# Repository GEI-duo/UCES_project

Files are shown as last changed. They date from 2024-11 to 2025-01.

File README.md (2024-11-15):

# UCES_project

## Parts

### Meeple

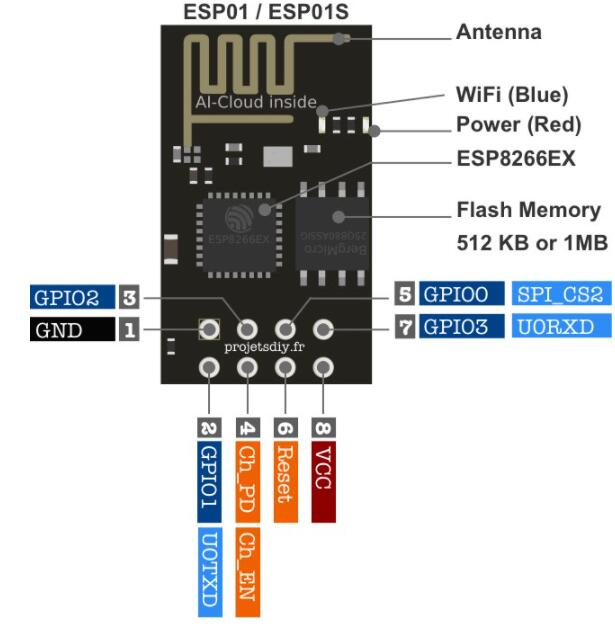
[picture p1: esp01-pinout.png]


#### Hardware

-   ESP-01 (ESP8266)
-   ESP-01 Programmer module
-   ESP-01 Bredboard adapter
-   Mini bredboard
-   Hall sensor (A3144)
-   Resistors
-   LED
-   Set of wires

### Operation base

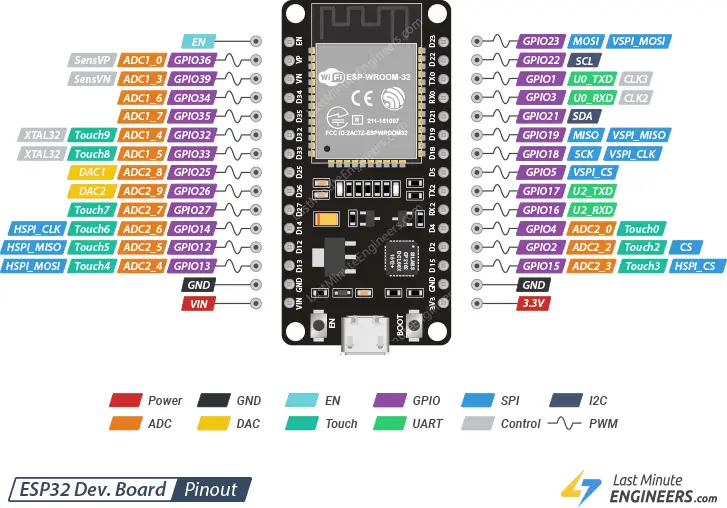
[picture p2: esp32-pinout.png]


#### Hardware

-   ESP-32
-   LCD Display
-   I2C - LCD Adapter
-   Buzzer
-   Push button
-   Resistors
-   Set of wires
-   Large bredboard

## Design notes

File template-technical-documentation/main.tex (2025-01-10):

\documentclass[11pt]{article}
\linespread{1.5}

% SELECT LANGUAGE:
\usepackage{preamble}
% \usepackage[spanish]{preamble}

% Help LaTeX Workshop citation browser parser
\iffalse
\addbibresource{bibliography.bib} 
\fi

\begin{document}

{
\pagenumbering{gobble} % Remove page numbering
\hypersetup{hidelinks} % Hide link colors

% Title
\subfile{title}

% Abstract
% \subfile{abstract}

\newpage

% Table of Contents
\tableofcontents
\clearpage

% List of *
% \tcblistof[\section*]{code}{\codListTitle}                    % codes
% \tcblistof[\section*]{theorem}{\theoListTitle}                % theorems
% \renewcommand{\listfigurename}{\figListTitle}\listoffigures   % figures
% \renewcommand\listtablename{\tabListTitle}\listoftables       % tables
}

\clearpage
\pagenumbering{arabic} % Add page numbering

% ------------------------- CONTENT ------------------------- %

\subfile{sections/wiring-schematic}
\subfile{sections/mqtt-topics}

% ---------------------------------------------------------- %

% Acronyms
% \printglossary[type=\acronymtype, title=\acrTitle]

% Special terms
% \printglossary[title=\terTitle]

% Bibliography
% \printbibliography[heading=bibintoc, title=\bibTitle]
% \clearpage

% Appendix
% \subfile{appendix}

\end{document}

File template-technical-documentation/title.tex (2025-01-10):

\documentclass[../main.tex]{subfiles}

\begin{document}

\begin{titlepage}
    \begin{minipage}[c]{0.4\linewidth}
    Universitat de Lleida \\
    Enginyeria Informàtica \\
    Embedded and Ubiquitous Systems \\
    Prof. Fernando Guirado Fernández
    \end{minipage}
    \hfill
    \begin{minipage}[c]{0.5\linewidth}
    \hfill
    
    \end{minipage}
        
    \vspace{5cm}

     \begin{center}
        \Huge
        \textbf{e-Game Board} \\ Meeple Showdown \\ \LARGE Technical Documentation
     \end{center}        
            
    \vspace{5cm}
        
    \begin{flushright}
        \large
        Jordi García Ventura \\
        Christian López García
    \end{flushright}
        
    \vfill
        
    \begin{center}
        \today
    \end{center}
\end{titlepage}

\end{document}

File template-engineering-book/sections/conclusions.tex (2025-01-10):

\documentclass[../main.tex]{subfiles}

\begin{document}

\section{Conclusions}

The game we developed is functional, but it currently does not account for certain unpredictable player behaviors, such as publishing to topics at inappropriate times.

Developing with microcontrollers is undoubtedly challenging, yet we successfully created an engaging and enjoyable game that integrates all the essential components of an embedded system. Additionally, we achieved interconnectivity among multiple devices through networking, unlocking numerous possibilities for future projects. For instance, the network capabilities could be leveraged to input user data via a captive portal rather than hardcoding network credentials into the source code. Another potential enhancement could be implementing Over-The-Air (OTA) updates, allowing remote updates to the devices' firmware.

A significant challenge we faced was establishing a robust communication standard, including a well-defined contract and MQTT topic structure, to ensure seamless interaction between devices. This standardization enabled different teams to work independently while ensuring all components integrated cohesively. Achieving this required a clear understanding of the project requirements and the components involved.

One obstacle that slowed our progress was the time required for compiling and uploading code to the microcontrollers, particularly with the ESP-01, which requires flashing via a USB-to-Serial adapter. Using a development-friendly board with a micro-USB interface could have expedited our iteration process. Once the code reached a more stable state, we could then transition to the ESP-01 for deployment.

Overall, this project provided valuable insights into the complexities of embedded systems and offered a foundation for exciting future developments.

\end{document}

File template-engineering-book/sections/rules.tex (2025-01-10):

\documentclass[../main.tex]{subfiles}

\begin{document}

\section{e-Game Rules}

\subsection{Objective}

Be the last surviving meeple on the board.

\subsection{Players}

Each team consists of two people:
\begin{itemize}
    \item \textbf{Mover (Pawn Controller)}: Controls the movement of the meeple on the board.
    \item \textbf{Operator (Strategist)}: Makes decisions on whether to shoot or pass the bullet without seeing the board.
\end{itemize}

\subsection{Game Components}
\begin{itemize}
    \item \textbf{Magnetic board(s)}: Includes hidden magnets under each position.
    \item \textbf{Meeples (pawns)}: Each player team has one meeple. It has two LEDs: one for knowing who has the bullet and another for magnet detection feedback.
    \item \textbf{Operation Base}: Includes LCD display, push button, and other components for decisions made by operators.
    \item \textbf{Broker}: Handles the game logic and the state.
\end{itemize}

\subsection{Setup}
\begin{itemize}
    \item \textbf{Initial Meeple Placement}: Each pawn begins in a random position on the board. This is decided before the game starts.
    \item \textbf{Bullet Assignment}: One player is randomly assigned the Bullet at the start of the game.
\end{itemize}

\subsection{Gameplay Overview}
The game proceeds in rounds, with the following steps repeated until only one meeple remains:
\begin{enumerate}
    \item \textbf{Movement Phase:}
    \begin{itemize}
        \item Pawns move one space in one of four directions: up, down, left, or right.
        \item Movement order is decided randomly at the start of each round.
    \end{itemize}
    \item \textbf{Decision Phase:}
    \begin{itemize}
        \item The operator of the team with the Bullet decides if they want to shoot.
        \item The operator cannot see the board, but may communicate with other pawns (within 60 seconds).
        \item Shooting affects all meeples in the same row, column, or diagonal as the operator's meeple (Figure \ref{fig:shooting}).
        \begin{itemize}
            \item \textbf{Hit}: If the shot hits any meeples, they are eliminated.
            \item \textbf{Miss}: If no other meeple is hit, the shooting operator is eliminated.
        \end{itemize}
        \item If the operator chooses not to shoot, there is a small probability of dying.
    \end{itemize}
\end{enumerate}

\begin{figure}[!htb]
    \centering
    }\
    \caption{Shooting directions examples}
    \label{fig:shooting}
\end{figure}

\subsection{Additional Rules}
\begin{itemize}
    \item \textbf{Time Constraints}: Operators must decide to shoot or not within 60 seconds. If time runs out, the decision is to not shoot.
    \item \textbf{Lives}: Each meeple has 1 life. If they are hit, they are eliminated.
    \item \textbf{Random Player Selection}: When the bullet is reassigned, the game selects a random player who hasn’t been eliminated.
\end{itemize}

\subsection{End Condition}
The game continues until only one meeple remains. This team is declared the winner.

\end{document}

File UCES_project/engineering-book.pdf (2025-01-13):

Universitat de Lleida

Enginyeria Informàtica

Embedded and Ubiquitous Systems

Prof. Fernando Guirado Fernández

# e-Game Board

# Meeple Showdown

## Engineering Book

Jordi García Ventura

Christian López García

January 10, 2025

## Contents

## 1 Project Milestones

The project needs to be done between the 19th of October 2024 and the 13th of January 2025.

We identify ve main features that need to be developed:

- Game Design
- MQTT Broker
- Meeple
- Operation base
- Master

All the tasks, subtasks, time estimations and dependencies are shown in the Gantt chart in

Figure 1.

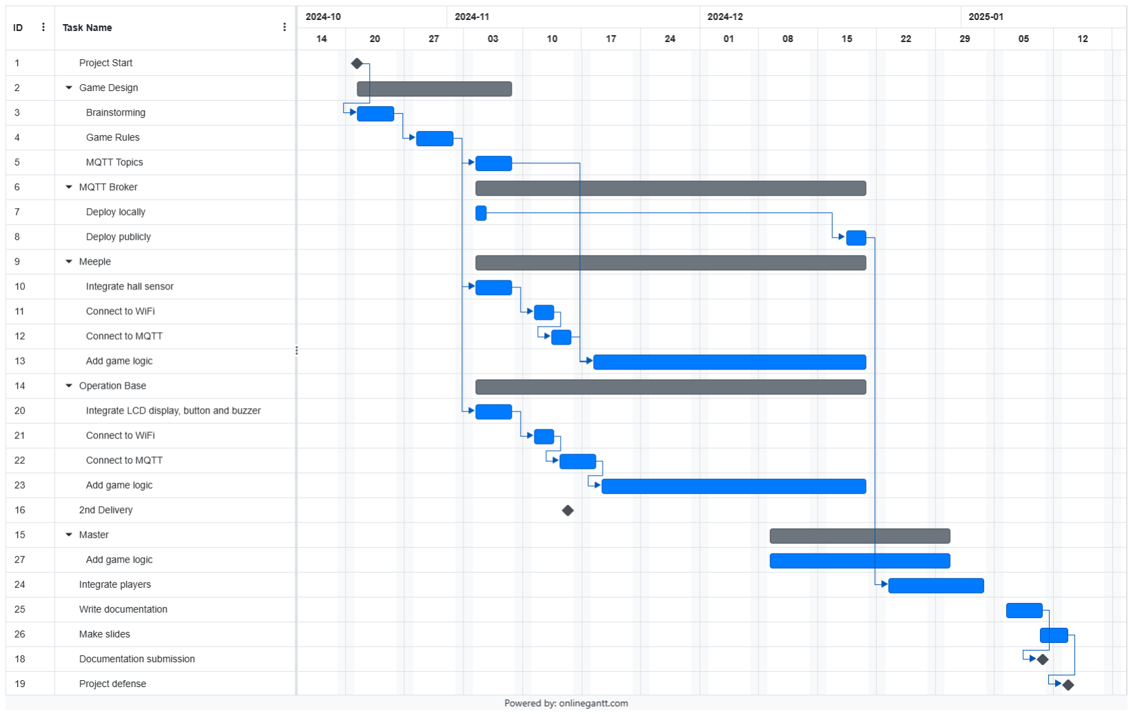
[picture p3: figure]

Figure 1: Gantt chart of the project

Regarding the asignations, the Game Design, Master and MQTT Broker are going to be

done by all members of the dierent teams. Then, each team is responsible of programming

their Meeple and Operation base. In our case, Christian will do the Meeple and Jordi will do the

Operation base.

Finally, we are going to expose the MQTT Broker in a public server in order to test the

communication between the devices of all the groups remotely.

## 2 Component Design

### 2.1 Meeple

The meeple is the component that represents the player’s position on the board and provides

feedback about player movement, death, and turn roles. It achieves this using two LEDs (a

green one and a yellow one) and a hall sensor. Communication with the game controller is

facilitated through the MQTT protocol.

The logic governing the meeple is depicted in Figure 2.

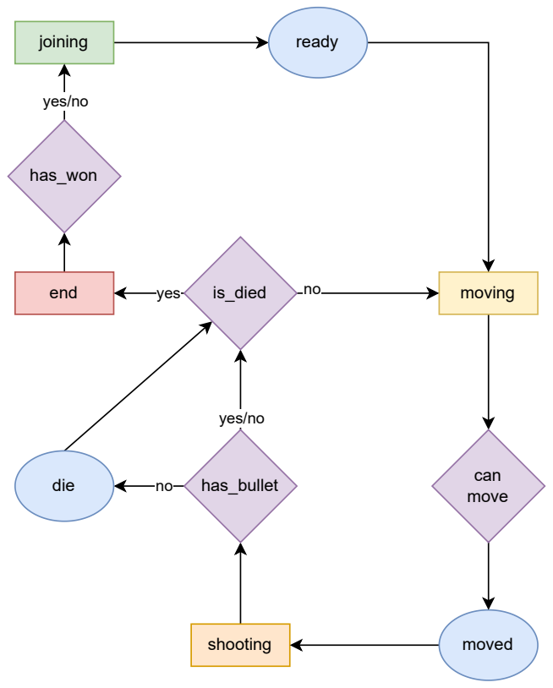
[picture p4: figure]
joining; moving; shooting; end; ready; moved; can move; yes/no; die; has_bullet; has_won; yes; is_died

Figure 2: Meeple logic ow diagram

Developing the meeple required approximately 10 hours and was completed solely by

Christian. While the component was relatively simple to design, my limited experience with

electronics and C++ made the process more time-consuming, particularly when trying to

create scalable and understandable code.

As mentioned earlier, the most challenging part was ensuring the C++ code worked as

intended. Another diculty was achieving the desired "blinking" eect for the green LED, which required ne-tuning to function properly.

### 2.2 Operation base

The operation base is responsible for determining, when it is its turn, whether the player should

shoot or not. Additionally, it provides feedback about the game state through an LCD display,

as the operator cannot directly see the game board.

The logic governing the operation base, which relies on MQTT topic subscription and

publication, is illustrated in Figure 3.

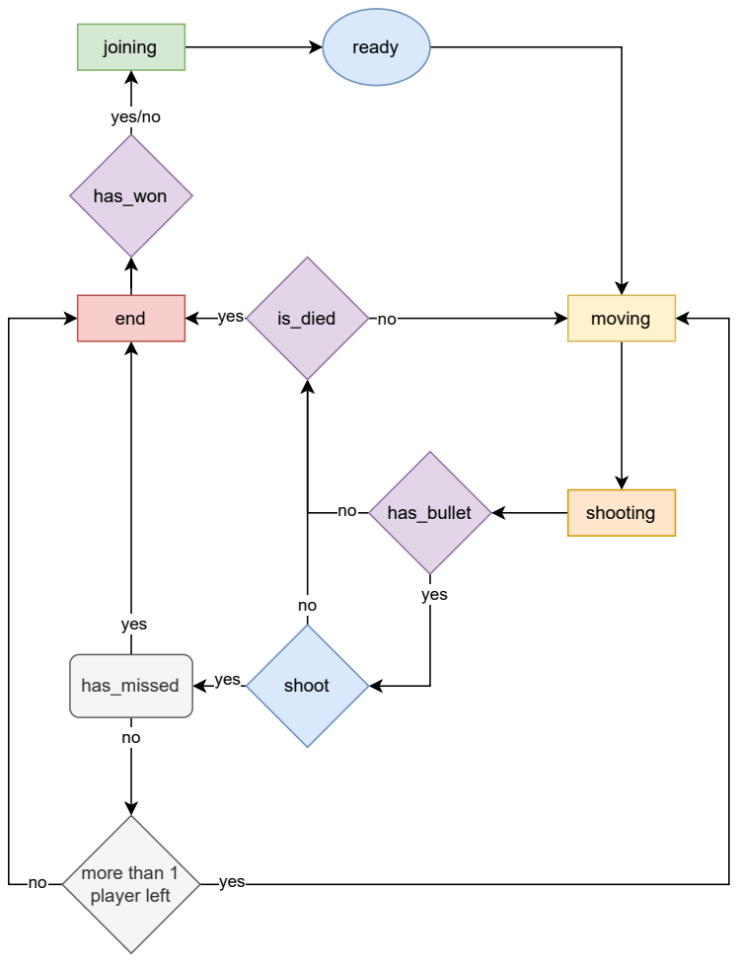
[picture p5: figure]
joining; ready; end; yes; has_bullet; moving; shooting; shoot; is_died; yes/no; has_won; has_missed; yes more than 1; player left

Figure 3: Operation base logic ow diagram

Developing the operation base required approximately 30 hours and was completed entirely

by Jordi.

Initially, all programming was done using Arduino. However, I later migrated most of the

code to FreeRTOS. During development, I encountered several challenges. One issue was with

the button, which behaved erratically. This was not solely due to switch bounce; interference

was also caused by the weak internal pull-up resistorsimply bringing a nger close to the button

without touching it aected the readings. Adding an external pull-up resistor resolved this

issue.

Another problem involved WiFi connectivity. The ESP32 module was unable to connect to

my network. After investigation, I discovered that the ESP32 does not support 5GHz networks,

requiring a switch to a 2.4GHz network.

I also faced diculties connecting to the MQTT broker. The issue stemmed from the

broker’s IP address changing, but the unclear error messages made diagnosing the problem

challenging.

Lastly, I dedicated considerable time to refactoring the code, improving its readability and

scalability for future maintenance and enhancements.

### 2.3 Game Controller

The game controller is the core component of the game, responsible for managing the game

ow, player turns, game state, and communication with the player feedback system. It operates

as a Docker container running a Python script that uses the MQTT protocol in a reactive

manner to enable bidirectional communication with the players.

The logic governing the game controller is illustrated in Figure 4.

Developing the game controller took approximately 20 hours and was completed solely by

Christian. We chose Python for the development because it didnt need to run on a microchip,

so performance wasnt a major concern. Additionally, Im more familiar with Python, despite

having no prior experience with the paho-mqtt library. The most challenging aspect was

designing a clean and maintainable project structure. I encountered issues with circular

imports while trying to make the code both modular and understandable, and I feel that I

struggled with this in some areas.

I developed the meeple and the game controller in parallel, which allowed me to test

communication between the two components. While this was benecial, I was unable to test

the game controller with any operation base, so Im uncertain if it functions as expected in that

regard.

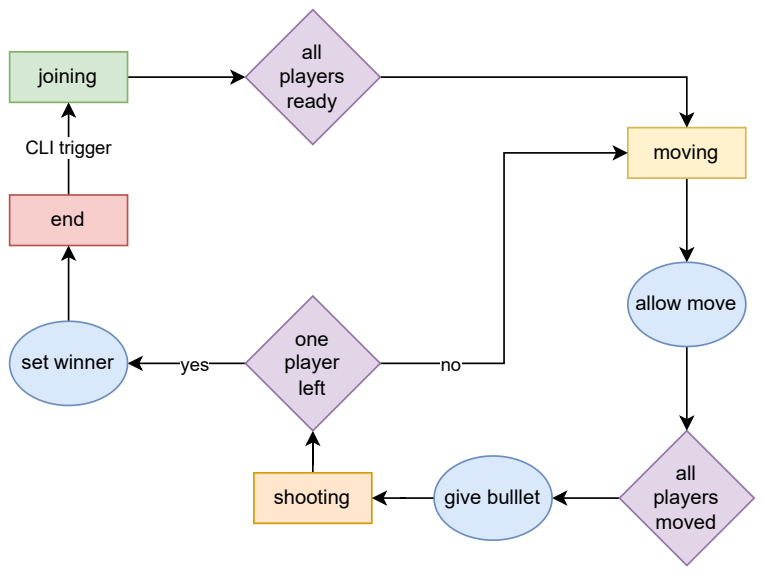
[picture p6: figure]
joining; moving; shooting; CLI trigger; end; all players ready; yes; one player left; all players moved; give bulllet; allow move; set winner

Figure 4: Master logic ow diagram

### 2.4 MQTT Broker

The MQTT broker is a critical component of the game, enabling seamless communication

between all other components. It operates as a Docker container running the Mosquitto MQTT

broker.

Developing the MQTT broker required approximately 4 hours and was completed solely by

Christian. The most challenging aspect was implementing authentication for the broker. The

team also encountered an issue where GitHub altered the line endings in conguration les

from LF to CRLF, which caused unexpected failures in the broker’s functionality.

Ultimately, Jordi deployed the broker to the cloud, allowing the team to test the game

remotely without needing to meet in person

## 3 e-Game Rules

### 3.1 Objective

Be the last surviving meeple on the board.

### 3.2 Players

Each team consists of two people:

- Mover (Pawn Controller): Controls the movement of the meeple on the board.
- Operator (Strategist): Makes decisions on whether to shoot or pass the bullet without

seeing the board.

### 3.3 Game Components

- Magnetic board(s): Includes hidden magnets under each position.
- Meeples (pawns): Each player team has one meeple. It has two LEDs: one for knowing

who has the bullet and another for magnet detection feedback.

- Operation Base: Includes LCD display, push button, and other components for decisions

made by operators.

- Broker: Handles the game logic and the state.

### 3.4 Setup

- Initial Meeple Placement: Each pawn begins in a random position on the board. This

is decided before the game starts.

- Bullet Assignment: One player is randomly assigned the Bullet at the start of the game.

### 3.5 Gameplay Overview

The game proceeds in rounds, with the following steps repeated until only one meeple remains:

1. Movement Phase:
- Pawns move one space in one of four directions: up, down, left, or right.
- Movement order is decided randomly at the start of each round.
2. Decision Phase:
- The operator of the team with the Bullet decides if they want to shoot.
- The operator cannot see the board, but may communicate with other pawns (within

60 seconds).

- Shooting aects all meeples in the same row, column, or diagonal as the operator’s

meeple (Figure 5).

– Hit: If the shot hits any meeples, they are eliminated.

– Miss: If no other meeple is hit, the shooting operator is eliminated.

- If the operator chooses not to shoot, there is a small probability of dying.

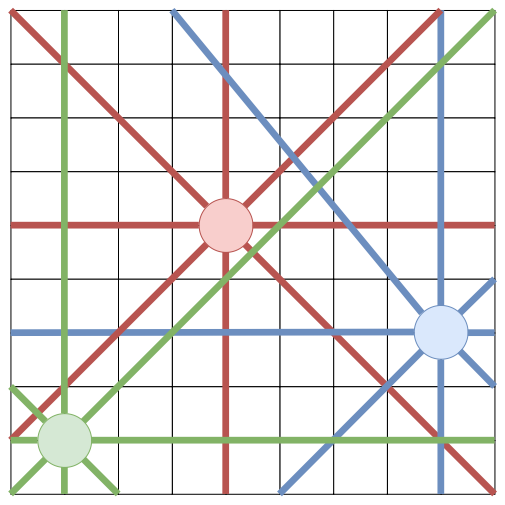
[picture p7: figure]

Figure 5: Shooting directions examples

### 3.6 Additional Rules

- Time Constraints: Operators must decide to shoot or not within 60 seconds. If time

runs out, the decision is to not shoot.

- Lives: Each meeple has 1 life. If they are hit, they are eliminated.
- Random Player Selection: When the bullet is reassigned, the game selects a random

player who hasnt been eliminated.

### 3.7 End Condition

The game continues until only one meeple remains. This team is declared the winner.

## 4 Conclusions

The game we developed is functional, but it currently does not account for certain unpredictable

player behaviors, such as publishing to topics at inappropriate times.

Developing with microcontrollers is undoubtedly challenging, yet we successfully created

an engaging and enjoyable game that integrates all the essential components of an embedded

system. Additionally, we achieved interconnectivity among multiple devices through network-

ing, unlocking numerous possibilities for future projects. For instance, the network capabilities

could be leveraged to input user data via a captive portal rather than hardcoding network

credentials into the source code. Another potential enhancement could be implementing

Over-The-Air (OTA) updates, allowing remote updates to the devices’ rmware.

A signicant challenge we faced was establishing a robust communication standard, includ-

ing a well-dened contract and MQTT topic structure, to ensure seamless interaction between

devices. This standardization enabled dierent teams to work independently while ensuring

all components integrated cohesively. Achieving this required a clear understanding of the

project requirements and the components involved.

One obstacle that slowed our progress was the time required for compiling and uploading

code to the microcontrollers, particularly with the ESP-01, which requires ashing via a USB-

to-Serial adapter. Using a development-friendly board with a micro-USB interface could have

expedited our iteration process. Once the code reached a more stable state, we could then

transition to the ESP-01 for deployment.

Overall, this project provided valuable insights into the complexities of embedded systems

and oered a foundation for exciting future developments.

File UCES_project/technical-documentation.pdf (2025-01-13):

Universitat de Lleida

Enginyeria Informàtica

Embedded and Ubiquitous Systems

Prof. Fernando Guirado Fernández

# e-Game Board

# Meeple Showdown

## Technical Documentation

Jordi García Ventura
Christian López García

January 10, 2025

### Contents

### 1 Component wiring schematics

### 1.1 Meeple

It consists on 2 LEDs, a green one and a yellow one, a hall sensor, a microcontroller (ESP-01)

and a battery, as in the Figure 1. Each component has the following function:

1. ESP-01: Microcontroller that controls the LEDs, reads the Hall Sensor and reads/writes

feedback with MQTT.

2. Battery: Power source for the ESP-01
3. Hall Sensor: Detects when the meeple is being detected on board, detects meeple

movement and death.

4. Green LED: Has two modes, when blinking it indicates that it’s the meeple turn for

moving, when solid it indicates the hall sensor is detecting a magnetic eld (the meeple

is detecting the board).

5. Yellow LED: Indicates if the player has the bullet on the shooting stage.

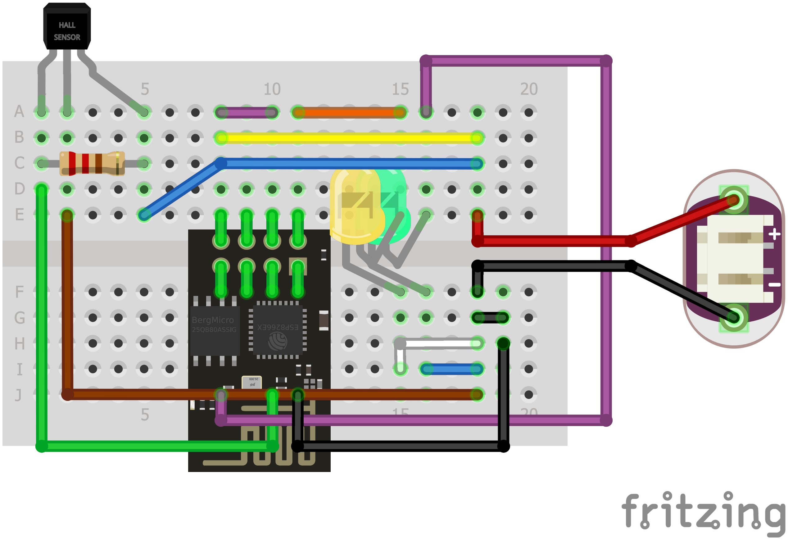
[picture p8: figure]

Figure 1: Meeple components schematic

### 1.2 Operation base

It consists on a red LED, a button, a buzzer, a microcontroller (ESP-32) and a LCD screen

connected through a I2C module, as shown in the Figure 2. Each component has the following

function:

1. ESP-32: Microcontroller that controls the LCD screen, reads the button, reads/writes

feedback with MQTT (through WiFi) and controls the buzzer.

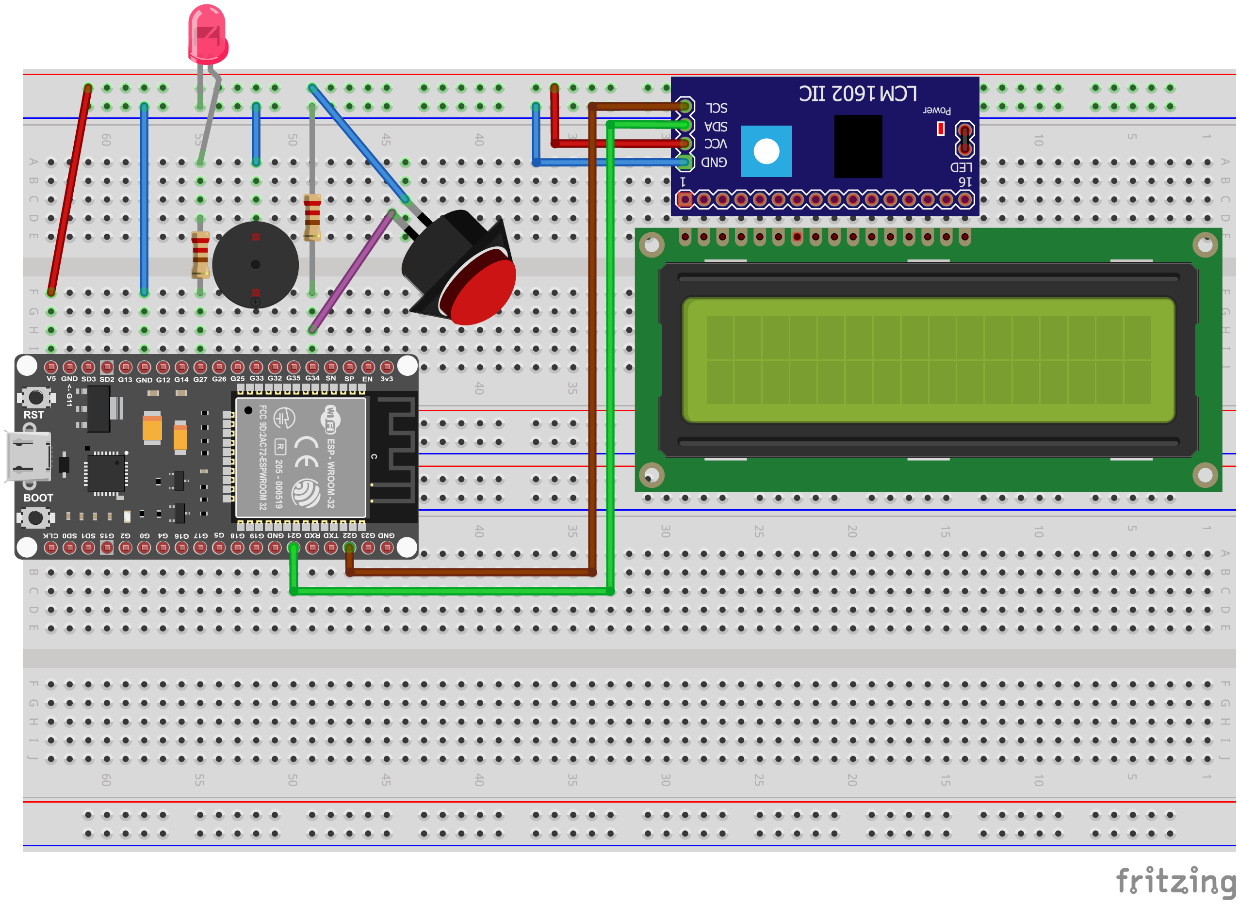
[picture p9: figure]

Figure 2: Operation base components schematic

2. LCD screen: Displays the current game stage and the player’s turn.
3. Button: Used to shoot the bullet.
4. Buzzer: Indicates the end of the game.
5. Red LED: Indicates whether the player has the bullet.
6. I2C module: Module that connects the ESP-32 with the LCD screen through I2C proto-

col.

7. Resistors: Both resistors are 220 Ohm and are used to limit the current.

The board can be powered through a Micro-USB cable from a computer USB port.

### 2 MQTT topics

We can see the used MQTT topics in Figure 3, dened specically in Section 2.1, 2.2.

### 2.1 Player topics

With the base topic players/<player_id>/, where player_id is the player’s predened unique

identier (e.g. in our case duo_jc), we have the following separated topics, where the actions

subtopics are used to send feedback from the players and the state subtopics are used to receive

players | {player_id} | actions | die | bool
| | | shoot | bool
| | | move | bool
ready | meeple | bool
| base | bool
state | has_bullet | bool
| has_won | bool
| can_move | bool
| has_died | bool
state | stage | "joining" | "moving" | "shooting" | "end"

Figure 3: MQTT topics resume

feedback from the game controller:

Player actions topics:

- actions/die: bool. Indicates the player’s death.
- actions/move: bool. Indicates the player’s movement.
- actions/shoot: bool. Indicates the player’s shooting decision.
- actions/ready/meeple: bool. Indicates the player’s meeple is ready.
- actions/ready/base: bool. Indicates the player’s base is ready.

Player state topics:

- state/has_bullet: bool. Indicates if the player has the bullet.
- state/has_won: bool. Indicates if the player is the last alive.
- state/has_died: bool. Indicates if the player has died.
- state/can_move: bool. Indicates if it’s the player’s turn to move.

### 2.2 State topics

With the base topic state/, we have the following topics:

- stage: "joining" | "moving" | "shooting" | "end". Indicates the current game stage for all the

players.

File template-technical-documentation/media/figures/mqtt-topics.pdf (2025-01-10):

players

actions

state

| | | die | bool
| | | shoot | bool
| | | move | bool
ready | meeple | bool
| base | bool
| has_bullet | bool
| has_won | bool
| can_move | bool
| has_died | bool
state | stage | "joining" | "moving" | "shooting" | "end"

{player_id}

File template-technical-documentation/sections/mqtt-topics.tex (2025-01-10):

\documentclass[../main.tex]{subfiles}

\begin{document}

\section{MQTT topics}

We can see the used MQTT topics in \textbf{Figure \ref{fig:mqtt-topics}}, defined specifically in \textbf{Section \ref{sec:player-topics}, \ref{sec:state-topics}}.

\subsection{Player topics}
\label{sec:player-topics}

With the base topic \textbf{players/<player\_id>/}, where \textit{player\_id} is the player's predefined unique identifier (e.g. in our case \textit{duo\_jc}), we have the following separated topics, where the \textit{actions} subtopics are used to send feedback from the players and the \textit{state} subtopics are used to receive feedback from the game controller:

Player actions topics:
\begin{itemize}
    \item \textbf{actions/die}: \textit{bool}. Indicates the player's death.
    \item \textbf{actions/move}: \textit{bool}. Indicates the player's movement.
    \item \textbf{actions/shoot}: \textit{bool}. Indicates the player's shooting decision.
    \item \textbf{actions/ready/meeple}: \textit{bool}. Indicates the player's meeple is ready.
    \item \textbf{actions/ready/base}: \textit{bool}. Indicates the player's base is ready.
\end{itemize}

Player state topics:
\begin{itemize}
    \item \textbf{state/has\_bullet}: \textit{bool}. Indicates if the player has the bullet.
    \item \textbf{state/has\_won}: \textit{bool}. Indicates if the player is the last alive.
    \item \textbf{state/has\_died}: \textit{bool}. Indicates if the player has died.
    \item \textbf{state/can\_move}: \textit{bool}. Indicates if it's the player's turn to move.
\end{itemize}

\subsection{State topics}
\label{sec:state-topics}

With the base topic \textbf{state/}, we have the following topics:

\begin{itemize}
    \item \textbf{stage}: \textit{"joining" | "moving" | "shooting" | "end"}. Indicates the current game stage for all the players.
\end{itemize}

\begin{figure}
    \centering
    
    \caption{MQTT topics resume}
    \label{fig:mqtt-topics}
\end{figure}

\end{document}

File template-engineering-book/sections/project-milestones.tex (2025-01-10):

\documentclass[../main.tex]{subfiles}

\begin{document}

\section{Project Milestones}

The project needs to be done between the 19th of October 2024 and the 13th of January 2025. We identify five main features that need to be developed:
\begin{itemize}
    \item Game Design
    \item MQTT Broker
    \item Meeple
    \item Operation base
    \item Master
\end{itemize}
    
All the tasks, subtasks, time estimations and dependencies are shown in the Gantt chart in Figure \ref{fig:gantt}.

\begin{figure}[!htb]
    \centering
    }\
    \caption{Gantt chart of the project}
    \label{fig:gantt}
\end{figure}

Regarding the asignations, the \textit{Game Design}, \textit{Master} and \textit{MQTT Broker} are going to be done by all members of the different teams. Then, each team is responsible of programming their \textit{Meeple} and \textit{Operation base}.  In our case, Christian will do the \textit{Meeple} and Jordi will do the \textit{Operation base}.

Finally, we are going to expose the MQTT Broker in a public server in order to test the communication between the devices of all the groups remotely.

\end{document}

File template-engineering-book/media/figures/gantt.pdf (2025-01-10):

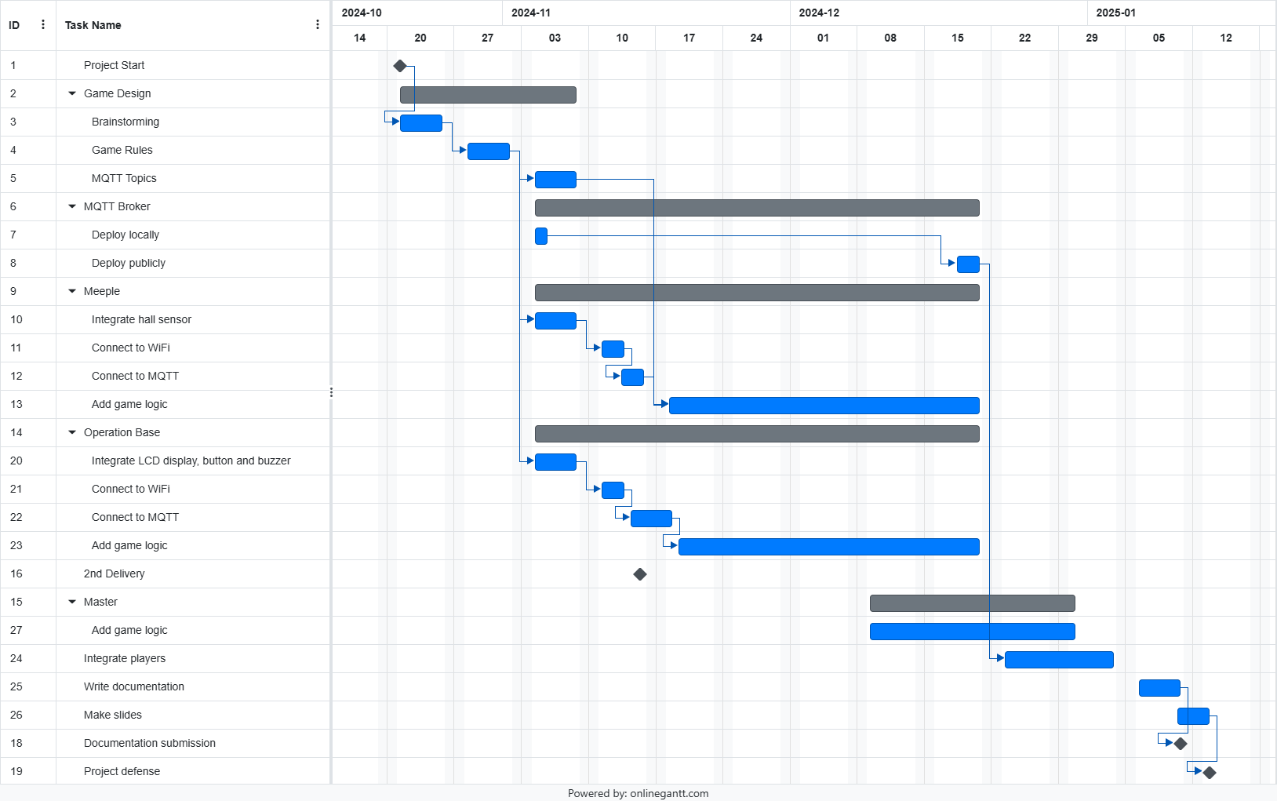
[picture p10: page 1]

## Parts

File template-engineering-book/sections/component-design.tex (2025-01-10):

\documentclass[../main.tex]{subfiles}

\begin{document}

\section{Component Design}

\subsection{Meeple}

The meeple is the component that represents the player's position on the board and provides feedback about player movement, death, and turn roles. It achieves this using two LEDs (a green one and a yellow one) and a hall sensor. Communication with the game controller is facilitated through the MQTT protocol.

The logic governing the meeple is depicted in Figure \ref{fig:meeple-logic}.

\begin{figure}[!htb]
    \centering
    }
    \caption{Meeple logic flow diagram}
    \label{fig:meeple-logic}
\end{figure}

Developing the meeple required approximately 10 hours and was completed solely by Christian. While the component was relatively simple to design, my limited experience with electronics and C++ made the process more time-consuming, particularly when trying to create scalable and understandable code.

As mentioned earlier, the most challenging part was ensuring the C++ code worked as intended. Another difficulty was achieving the desired "blinking" effect for the green LED, which required fine-tuning to function properly.

\subsection{Operation base}

The operation base is responsible for determining, when it is its turn, whether the player should shoot or not. Additionally, it provides feedback about the game state through an LCD display, as the operator cannot directly see the game board.

The logic governing the operation base, which relies on MQTT topic subscription and publication, is illustrated in Figure \ref{fig:base-logic}.

\begin{figure}[!htb]
    \centering
    }
    \caption{Operation base logic flow diagram}
    \label{fig:base-logic}
\end{figure}

Developing the operation base required approximately 30 hours and was completed entirely by Jordi.

Initially, all programming was done using Arduino. However, I later migrated most of the code to FreeRTOS. During development, I encountered several challenges. One issue was with the button, which behaved erratically. This was not solely due to switch bounce; interference was also caused by the weak internal pull-up resistor—simply bringing a finger close to the button without touching it affected the readings. Adding an external pull-up resistor resolved this issue.

Another problem involved WiFi connectivity. The ESP32 module was unable to connect to my network. After investigation, I discovered that the ESP32 does not support 5GHz networks, requiring a switch to a 2.4GHz network.

I also faced difficulties connecting to the MQTT broker. The issue stemmed from the broker's IP address changing, but the unclear error messages made diagnosing the problem challenging.

Lastly, I dedicated considerable time to refactoring the code, improving its readability and scalability for future maintenance and enhancements.

\subsection{Game Controller}

The game controller is the core component of the game, responsible for managing the game flow, player turns, game state, and communication with the player feedback system. It operates as a Docker container running a Python script that uses the MQTT protocol in a reactive manner to enable bidirectional communication with the players.

The logic governing the game controller is illustrated in Figure \ref{fig:master-logic}.

\begin{figure}[!htb]
    \centering
    }
    \caption{Master logic flow diagram}
    \label{fig:master-logic}
\end{figure}

Developing the game controller took approximately 20 hours and was completed solely by Christian. We chose Python for the development because it didn’t need to run on a microchip, so performance wasn’t a major concern. Additionally, I’m more familiar with Python, despite having no prior experience with the paho-mqtt library. The most challenging aspect was designing a clean and maintainable project structure. I encountered issues with circular imports while trying to make the code both modular and understandable, and I feel that I struggled with this in some areas.

I developed the meeple and the game controller in parallel, which allowed me to test communication between the two components. While this was beneficial, I was unable to test the game controller with any operation base, so I’m uncertain if it functions as expected in that regard.

\subsection{MQTT Broker}

The MQTT broker is a critical component of the game, enabling seamless communication between all other components. It operates as a Docker container running the Mosquitto MQTT broker.

Developing the MQTT broker required approximately 4 hours and was completed solely by Christian. The most challenging aspect was implementing authentication for the broker. The team also encountered an issue where GitHub altered the line endings in configuration files from LF to CRLF, which caused unexpected failures in the broker's functionality.

Ultimately, Jordi deployed the broker to the cloud, allowing the team to test the game remotely without needing to meet in person

\end{document}

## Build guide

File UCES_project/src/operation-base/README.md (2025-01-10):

# Operation Base

## Game

### Objective
Be the last surviving meeple on the board.

### Players
Each team consists of two people:
- Mover (Pawn Controller): Controls the movement of the meeple on the board.
- Operator (Strategist): Makes decisions on whether to shoot or pass the bullet without seeing the board.

### Game components
- Magnetic board(s) with hidden magnets under each position.
- Meeples (pawns): each player team has one meeple. It has two leds, one for knowing who has the bullet and another for the magnet detection feedback.
- Operation Base: includes LCD display, push button, and other components for decisions made by operators.
- Broker: it handles the game logic and the state.

### Setup
- Initial Meeple Placement: Each pawn begins in a random position on the board. This is decided before the game starts.
- Bullet Assignment: One player is randomly assigned the Bullet at the start of the game.

### Game Flow
The game proceeds in rounds, with the following steps repeated until only one meeple remains:
1. Movement Phase:
    - Pawns move one space in one of four directions: up, down, left, or right.
    - Movement order is decided randomly at the start of each round.
2. Decision Phase:
    - The operator of the team with the Bullet decides if they want to shoot.
    - The operator cannot see the board, but may communicate with other pawns (within 60 seconds).
    - Shooting affects all meeples in the same row, column or diagonal as the operator’s meeple.
        - Hit: If the shot hits any meeples, they are eliminated.
        - Miss: If no other meeple is hit, the shooting operator is eliminated.
    - If the operator chooses not to shoot, he has a small probability of dying.

## MQTT Topics
players/{player_id}
                    /actions
                        /die: bool
                        /shoot: bool
                        /move: bool
                        /ready
                            /meeple: bool
                            /base: bool
                    /state
                        /has_bullet: bool
                        /has_won: bool
                        /can_move: bool
                        /had_died: bool
state/stage: "joining" | "moving" | "shooting" | "end" 

### End condition
The game continues until only one meeple remains. This team is declared the winner.

## Project structure
/src
    main.cpp
    /tasks
        wifi_task.cpp
        wifi_task.h
            void wifiTask(void* pvParameters);
        mqtt_task.cpp
        mqtt_task.h
            void mqttTask(void* pvParameters);
        button_task.cpp
        button_task.h
            void buttonTask(void* pvParameters);
    /managers
        WifiManager.cpp
        WifiManager.h
            void setupWifi();
            void loopWifi();
        MqttManager.cpp
        MqttManager.h
            class MqttManager;
            void setupMqtt(PubSubClient& client);
            void reconnectMqtt(PubSubClient& client);
            void mqttCallback(char* topic, byte* payload, unsigned int length);

    /controllers
        ButtonController.cpp
        ButtonController.h
            void setupButton(void (*onClick)());
            void loopButton();
        LcdController.cpp
        LcdController.h
            void setupLcd();
        BuzzerController.cpp
        BuzzerController.h
            void setupBuzzer();
        LedController.cpp
        LedController.h
            void setupLed();
    config.h
    config.cpp
    globals.h
    globals.cpp

## Program flow
1. The `broker` sets the "joining" stage.                       
2. The `base` and the `meeple` can send their "ready" state.
3. When all players are ready, the `broker` changes the state to "moving".
4. While not all players have moved:
    4.1. The `broker` set the "can_move" state to true to the next player.
    4.2. The `meeple` sets the "move" state to true after moving.
5. After all players have moved, the `broker` changes the state to "shooting".
6. The `broker` sets the "has_bullet" state to true to a random player.
7. The `base` sets the "shoot" state to decide the shooting.
8. The `meeple`s send the "die" action if they were hit.
9. If no player was hit (10s after shooting), the `broker` sets the "had_died" state to true to the shooting player.
10. If there is only one player remaining, the `broker` changes the state to "end" and sets the "has_won" state to true to the winner.
11. Repeat steps 3 to 10 until the game ends.

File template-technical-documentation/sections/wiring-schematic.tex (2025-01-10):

\documentclass[../main.tex]{subfiles}

\begin{document}

\section{Component wiring schematics}

\subsection{Meeple}

It consists on 2 LEDs, a green one and a yellow one, a hall sensor, a microcontroller (ESP-01) and a battery, as in the \textbf{Figure \ref{fig:meeple}}. Each component has the following function:

\begin{enumerate}
    \item \textbf{ESP-01}: Microcontroller that controls the LEDs, reads the Hall Sensor and reads/writes feedback with MQTT.
    \item \textbf{Battery}: Power source for the ESP-01
    \item \textbf{Hall Sensor}: Detects when the meeple is being detected on board, detects meeple movement and death.
    \item \textbf{Green LED}: Has two modes, when blinking it indicates that it's the meeple turn for moving, when solid it indicates the hall sensor is detecting a magnetic field (the meeple is detecting the board).
    \item \textbf{Yellow LED}: Indicates if the player has the bullet on the shooting stage.
\end{enumerate}

\begin{figure}[!htb]
    \centering
    
    \caption{Meeple components schematic}
    \label{fig:meeple}
\end{figure}

\subsection{Operation base}

It consists on a red LED, a button, a buzzer, a microcontroller (ESP-32) and a LCD screen connected through a I2C module, as shown in the \textbf{Figure \ref{fig:base}}. Each component has the following function:

\begin{enumerate}
    \item \textbf{ESP-32}: Microcontroller that controls the LCD screen, reads the button, reads/writes feedback with MQTT (through WiFi) and controls the buzzer.
    \item \textbf{LCD screen}: Displays the current game stage and the player's turn.
    \item \textbf{Button}: Used to shoot the bullet.
    \item \textbf{Buzzer}: Indicates the end of the game.
    \item \textbf{Red LED}: Indicates whether the player has the bullet.
    \item \textbf{I2C module}: Module that connects the ESP-32 with the LCD screen through I2C protocol.
    \item \textbf{Resistors}: Both resistors are 220 Ohm and are used to limit the current.
\end{enumerate}

The board can be powered through a Micro-USB cable from a computer USB port.

\begin{figure}
    \centering
    
    \caption{Operation base components schematic}
    \label{fig:base}
\end{figure}

\end{document}

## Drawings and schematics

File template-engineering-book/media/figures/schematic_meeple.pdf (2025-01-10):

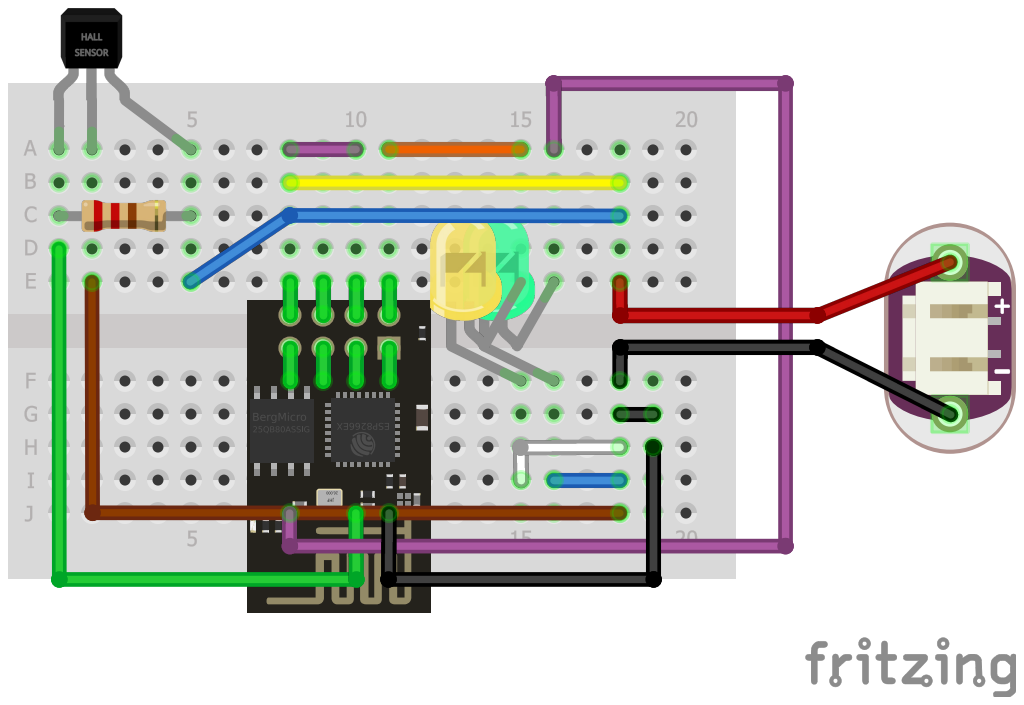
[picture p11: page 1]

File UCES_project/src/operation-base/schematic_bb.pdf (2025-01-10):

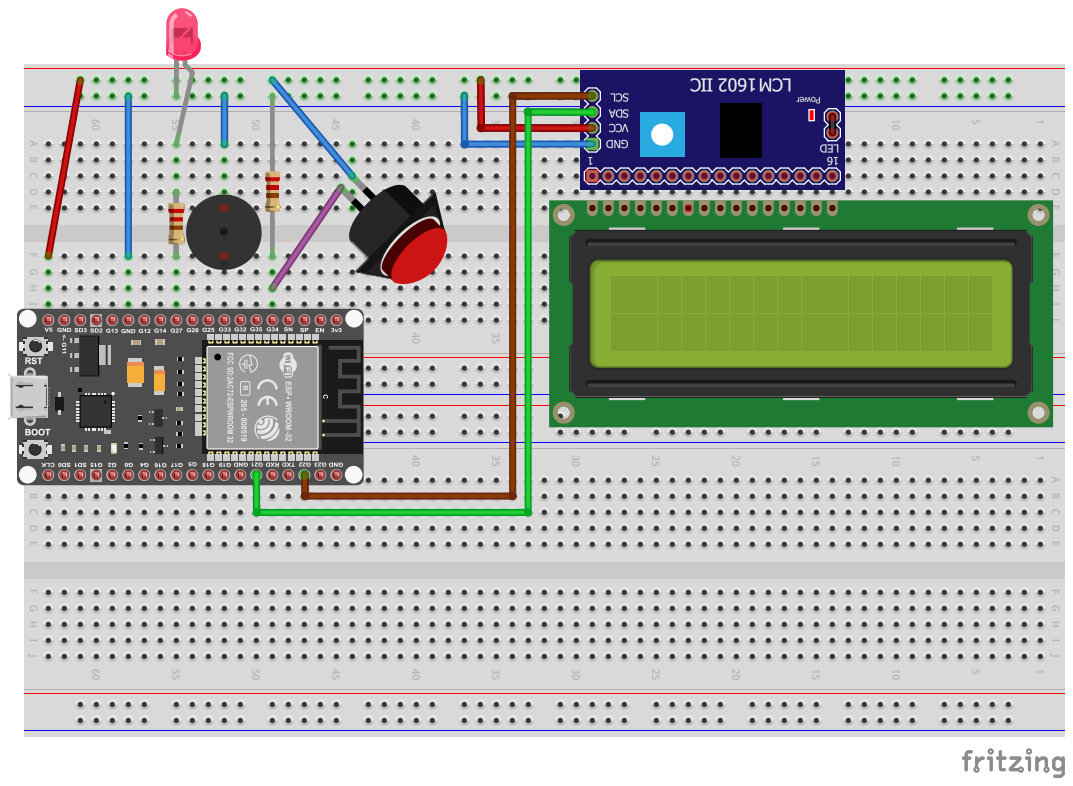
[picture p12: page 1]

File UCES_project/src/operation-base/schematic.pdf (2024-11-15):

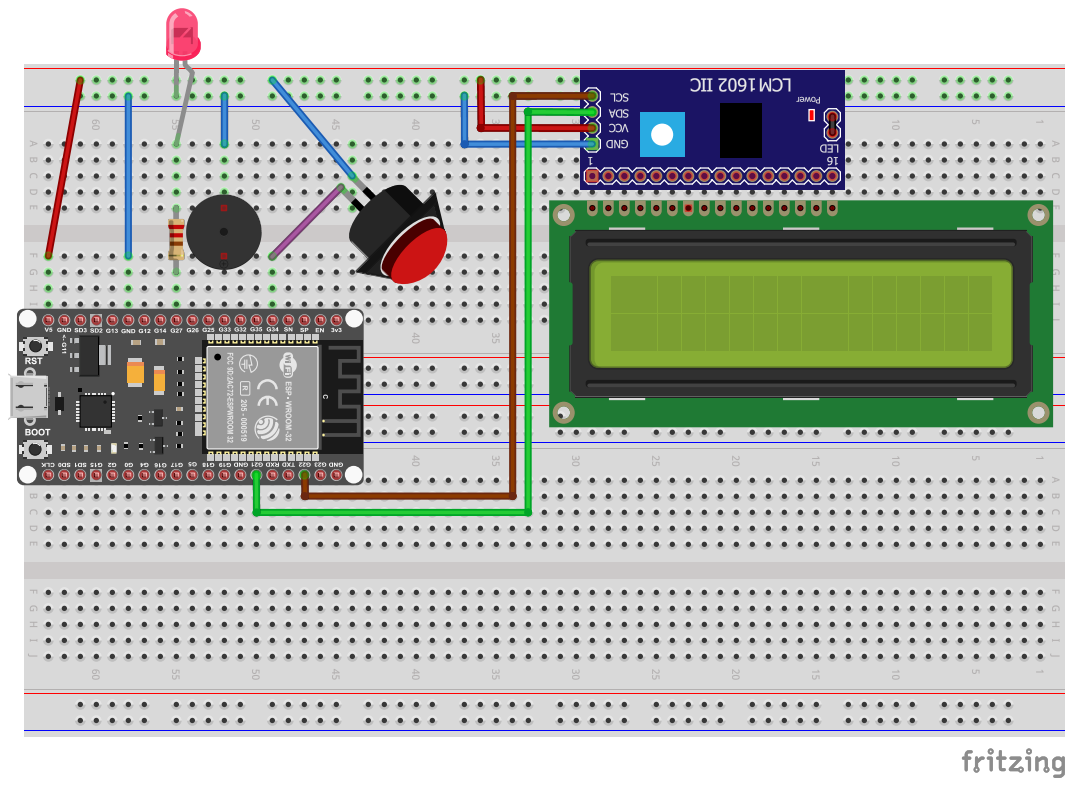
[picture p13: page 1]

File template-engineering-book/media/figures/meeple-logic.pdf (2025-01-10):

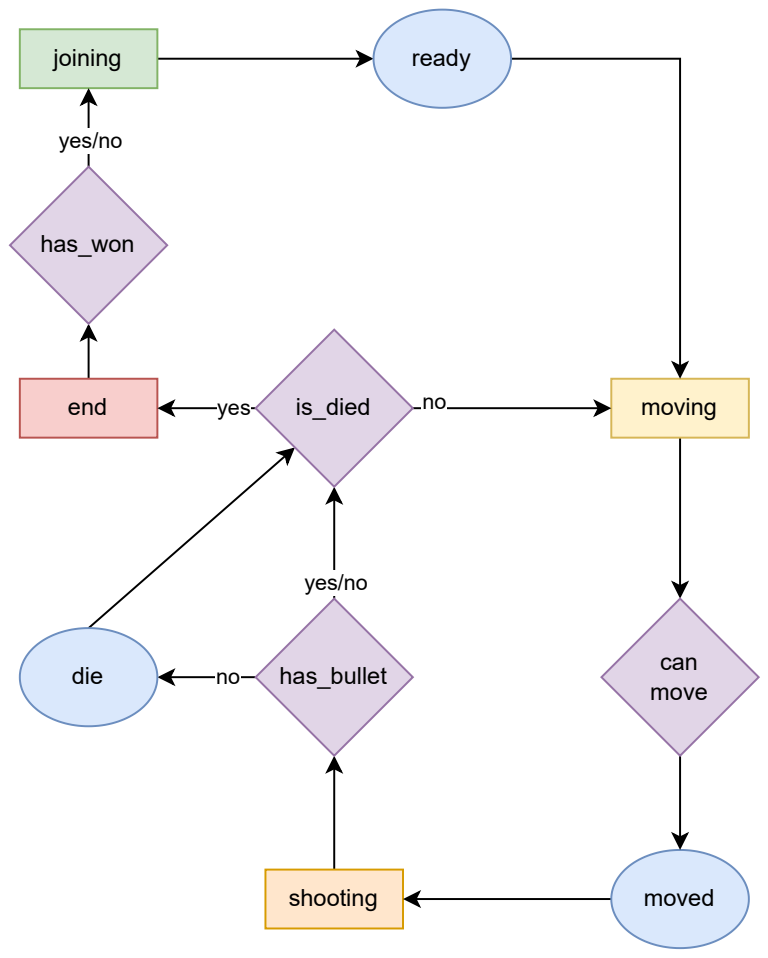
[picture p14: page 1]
joining; moving; shooting; end; ready; moved; can move; yes/no; die; has_bullet; has_won; yes; is_died

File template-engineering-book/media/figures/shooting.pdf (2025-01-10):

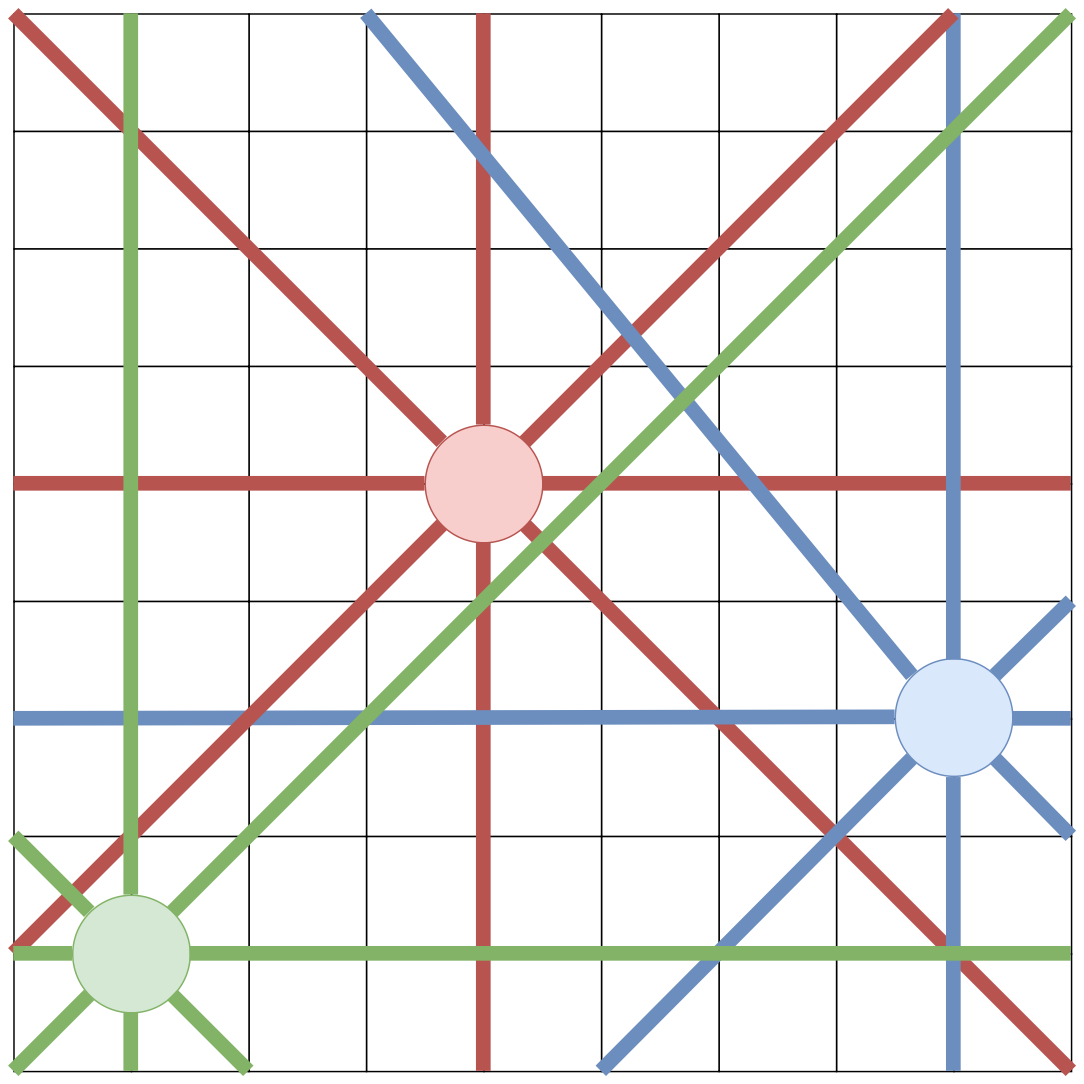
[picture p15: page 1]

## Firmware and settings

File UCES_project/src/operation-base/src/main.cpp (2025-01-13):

#include <Arduino.h>
#include <WiFi.h>
#include "config.h"
#include "controllers/ButtonController.h"
#include "controllers/LcdController.h"
#include "events.h"
#include "globals.h"
#include "managers/GameManager.h"
#include "managers/MqttManager.h"
#include "managers/WifiManager.h"

void onClickHandler() {
  Event event;
  event.type = EVENT_BUTTON_PRESS;
  event.data = NULL;

  xQueueSend(eventQueue, &event, portMAX_DELAY);
}

void setup() {
  Serial.begin(115200);

  wifiInit();
  mqttInit();

  setupButton(onClickHandler);
  setupLcd();
  eventQueue_init();

  setMsg("Press to join");

  xTaskCreate(wifiTask, "WiFi Task", 10000, NULL, 1, NULL);
  xTaskCreate(mqttTask, "MQTT Task", 10000, NULL, 1, NULL);
  xTaskCreate(buttonTask, "Button Task", 10000, NULL, 1, NULL);
  xTaskCreate(gameLoopTask, "Game Task", 10000, NULL, 1, NULL);
}

void loop() {}

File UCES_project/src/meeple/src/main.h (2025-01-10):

#pragma once

#include <ESP8266WiFi.h>
#include <Arduino.h>
#include <PubSubClient.h>

#include "WifiSetup.h"
#include "MqttSetup.h"
#include "Callbacks.h"
#include "GamePlayer.h"

#define PIN_HALL_SENSOR 2
#define PIN_FEEDBACK_MAGNETIC_LED 3
#define PIN_FEEDBACK_BULLET_LED 1 // IMPORTANT: Use 1 for playing 0 for debugging

#define LOOP_DELAY 0
#define WIFI_RECONNECT_DELAY_MS 1000

const char *SSID = "spinel";
const char *PASSWORD = "arieteariete";

const char *MQTT_HOST = "agrospai.udl.cat";
// const char *MQTT_HOST = "test.mosquitto.org";
const int MQTT_PORT = 1883;
const char *MQTT_USERNAME = "duo_jc";
const char *MQTT_PASSWORD = "VNbxst6n";

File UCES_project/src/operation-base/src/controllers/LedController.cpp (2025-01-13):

#include "LedController.h"
#include <Arduino.h>
#include "config.h"

void setupLed() {
  pinMode(LED_PIN, OUTPUT);
}

void turnOnLed() {
  digitalWrite(LED_PIN, HIGH);
}

void turnOffLed() {
  digitalWrite(LED_PIN, LOW);
}

void blinkTask(void* pvParameters) {
  while (true) {
    turnOnLed();
    vTaskDelay(1000 / portTICK_PERIOD_MS);
    turnOffLed();
    vTaskDelay(1000 / portTICK_PERIOD_MS);
  }
}

TaskHandle_t blinkTaskHandle = NULL;

void startBlinkTask() {
  xTaskCreate(blinkTask, "Blink Task", 10000, NULL, 1, &blinkTaskHandle);
}

void stopBlinkTask() {
  if (blinkTaskHandle != NULL) {
    vTaskDelete(blinkTaskHandle);
    turnOffLed();
    blinkTaskHandle = NULL;
  }
}

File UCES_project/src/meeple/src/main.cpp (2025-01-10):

#include "main.h"

int read_hall_sensor(void);

void write_feedback(const ulong);
void read_feedback(const ulong);

WiFiClient wifi_client;
PubSubClient mqtt_client(wifi_client);
Player player(MQTT_USERNAME, mqtt_client);
Callbacks cb(player);

const u16_t blink_interval = 750; // Blinking interval for the green LED (750 ms)
ulong green_time = 0;             // Time when the green LED was turned on

int hall_sensor = LOW;

void setup()
{
  Serial.begin(115200);
  pinMode(PIN_FEEDBACK_MAGNETIC_LED, OUTPUT);
  pinMode(PIN_FEEDBACK_BULLET_LED, OUTPUT);
  pinMode(PIN_HALL_SENSOR, INPUT);

  connect_wifi(SSID, PASSWORD, WIFI_RECONNECT_DELAY_MS);
  init_mqtt_client(mqtt_client, MQTT_HOST, MQTT_PORT, cb);
}

void loop()
{
  ulong t = millis();

  while (!mqtt_client.connected())
  {
    player.state = JOINING;
    player.set_has_bullet(false);
    player.set_has_won(false);
    player.set_can_move(false);
    player.set_has_died(false);

    digitalWrite(PIN_FEEDBACK_MAGNETIC_LED, LOW);
    digitalWrite(PIN_FEEDBACK_BULLET_LED, LOW);

    connect(mqtt_client, MQTT_USERNAME, MQTT_PASSWORD, 5000, cb);
    player.publish_ready();
  }

  read_feedback(t);
  write_feedback(t);

  mqtt_client.loop();

  delay(LOOP_DELAY);
}

int read_hall_sensor(void)
{
  return digitalRead(PIN_HALL_SENSOR) == LOW ? HIGH : LOW;
}

void read_feedback(const ulong t)
{
  const bool last_hall_sensor = hall_sensor;

  hall_sensor = read_hall_sensor();

  const bool is_hall_sensor_changed = last_hall_sensor != hall_sensor;

  if (is_hall_sensor_changed)
  {
    if (hall_sensor == HIGH)
    {
      // When joining magnetic field
      if (player.state == MOVING)
      {
        player.publish_moved();
        player.set_can_move(false);
      }
    }
    else
    {
      // When leaving magnetic field
      if (player.state == SHOOTING && !player.has_bullet())
      {
        player.publish_died();
      }
    }
  }
}

void write_feedback(const ulong t)
{
  // GREEN LED (Moving)
  if (player.can_move())
  {
    if (t > green_time)
    {
      digitalWrite(PIN_FEEDBACK_MAGNETIC_LED, hall_sensor);
      green_time = t + blink_interval;
    }
    else
    {
      digitalWrite(PIN_FEEDBACK_MAGNETIC_LED, LOW);
    }
  }
  else
  {
    // If won: Blink all lights
    if (player.has_won())
    {
      if (t > green_time)
      {
        digitalWrite(PIN_FEEDBACK_MAGNETIC_LED, HIGH);
        digitalWrite(PIN_FEEDBACK_BULLET_LED, HIGH);
        green_time = t + blink_interval;
      }
      else
      {
        digitalWrite(PIN_FEEDBACK_MAGNETIC_LED, LOW);
        digitalWrite(PIN_FEEDBACK_BULLET_LED, LOW);
      }
    }

    // GREEN LED if hall sensor
    digitalWrite(PIN_FEEDBACK_MAGNETIC_LED, hall_sensor);
  }

  // YELLOW LED (Bullet)
  digitalWrite(PIN_FEEDBACK_BULLET_LED, player.has_bullet() ? HIGH : LOW);
  // digitalWrite(PIN_FEEDBACK_BULLET_LED, HIGH);
}

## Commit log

2024-10-18 Hello world LED
2024-10-18 Magnet detection
2024-10-24 add schematic
    [schematic.fzz]
2024-11-15 add first working iteration
    [schematic.fzz]
2024-11-15 add schematics
2024-11-15 Fixed topic subscription + callbacks
    [main.cpp, main.h]
2024-11-21 Fixed pins and animation
    [main.cpp, main.h]
2024-12-22 first attempt with arduino
2025-01-10 fix schematic
2025-01-10 Wiring documentation and MQTT topics
2025-01-13 add last changes
    [schematic.fzz]
